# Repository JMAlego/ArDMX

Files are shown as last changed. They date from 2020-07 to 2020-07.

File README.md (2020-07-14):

# ArDMX

*DMX512 Interface Shield*

## Introduction
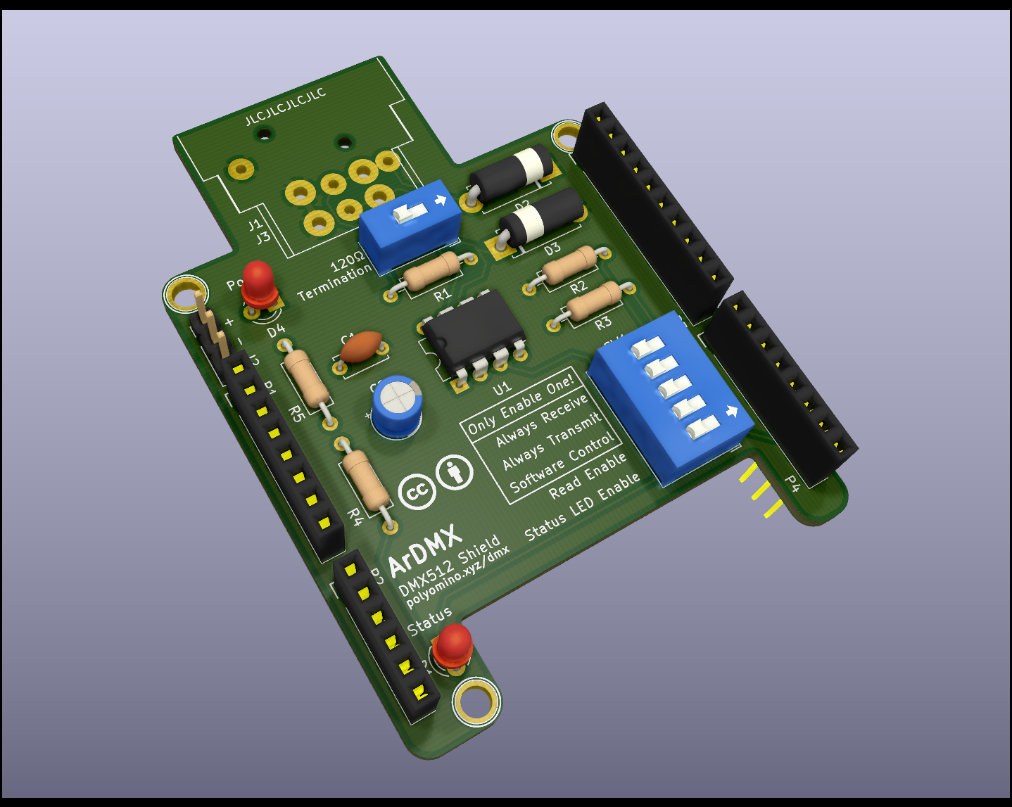
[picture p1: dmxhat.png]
Image of the DMX Shield


Following the creation of [AVR-DMX](https://github.com/JMAlego/AVR-DMX) for Arduino, I decided that my first foray into circuit board design should be the creation of a shield to work with AVR-DMX to allow proper interfacing of an Arduino to a DMX network.

**NB**: I have yet to actually get one of these made so who knows if it works, it's based on a perfboarded design that works correctly though.

## DIP Switches

- 120Ω Termination:
- Mode (only enable one unless you want a short):
  - Always Receive: Pull-down
  - Always Transmit: Pull-up
  - Software Control: Connect to pin 2
- Read Enable: Connect read output to pin 8
- Status LED Enable: Connect status LED to pin 9

## Optional Components

- D2 & D3 are only required for max voltage clamping on the DMX bus, if you're not worried about over/under-voltage then don't bother with them.
- SW2 & R1 are optional if you don't want 120Ω termination.
- J2 is not required if you don't want to use the outputs without the XLR connector.
- J1 is not required if you plan to use J2 to connect to the DMX network.
- Smoothing caps C1 & C2 are also optional if you're sure your input supply will be sufficiently smooth.
- D4 & R5 are optional if you don't want the power LED.
- Similarly, D1 & R4 are optional if you don't want the status LED.

## Rough Costing

It should be possible to build for around £10 or less (though you may need to make a few). You'll find the most expensive part is the Neutrik NC5FAH-DA (or compatible) XLR 5-pin connector.

As of revision 1.1 a cheaper option of using the 3-pin XLR Neutrik NC3FAH1-DA connector which the board now also supports.

## License

Hardware designs are licensed under the [Creative Commons Attribution 4.0 International Licence](https://creativecommons.org/licenses/by/4.0/).

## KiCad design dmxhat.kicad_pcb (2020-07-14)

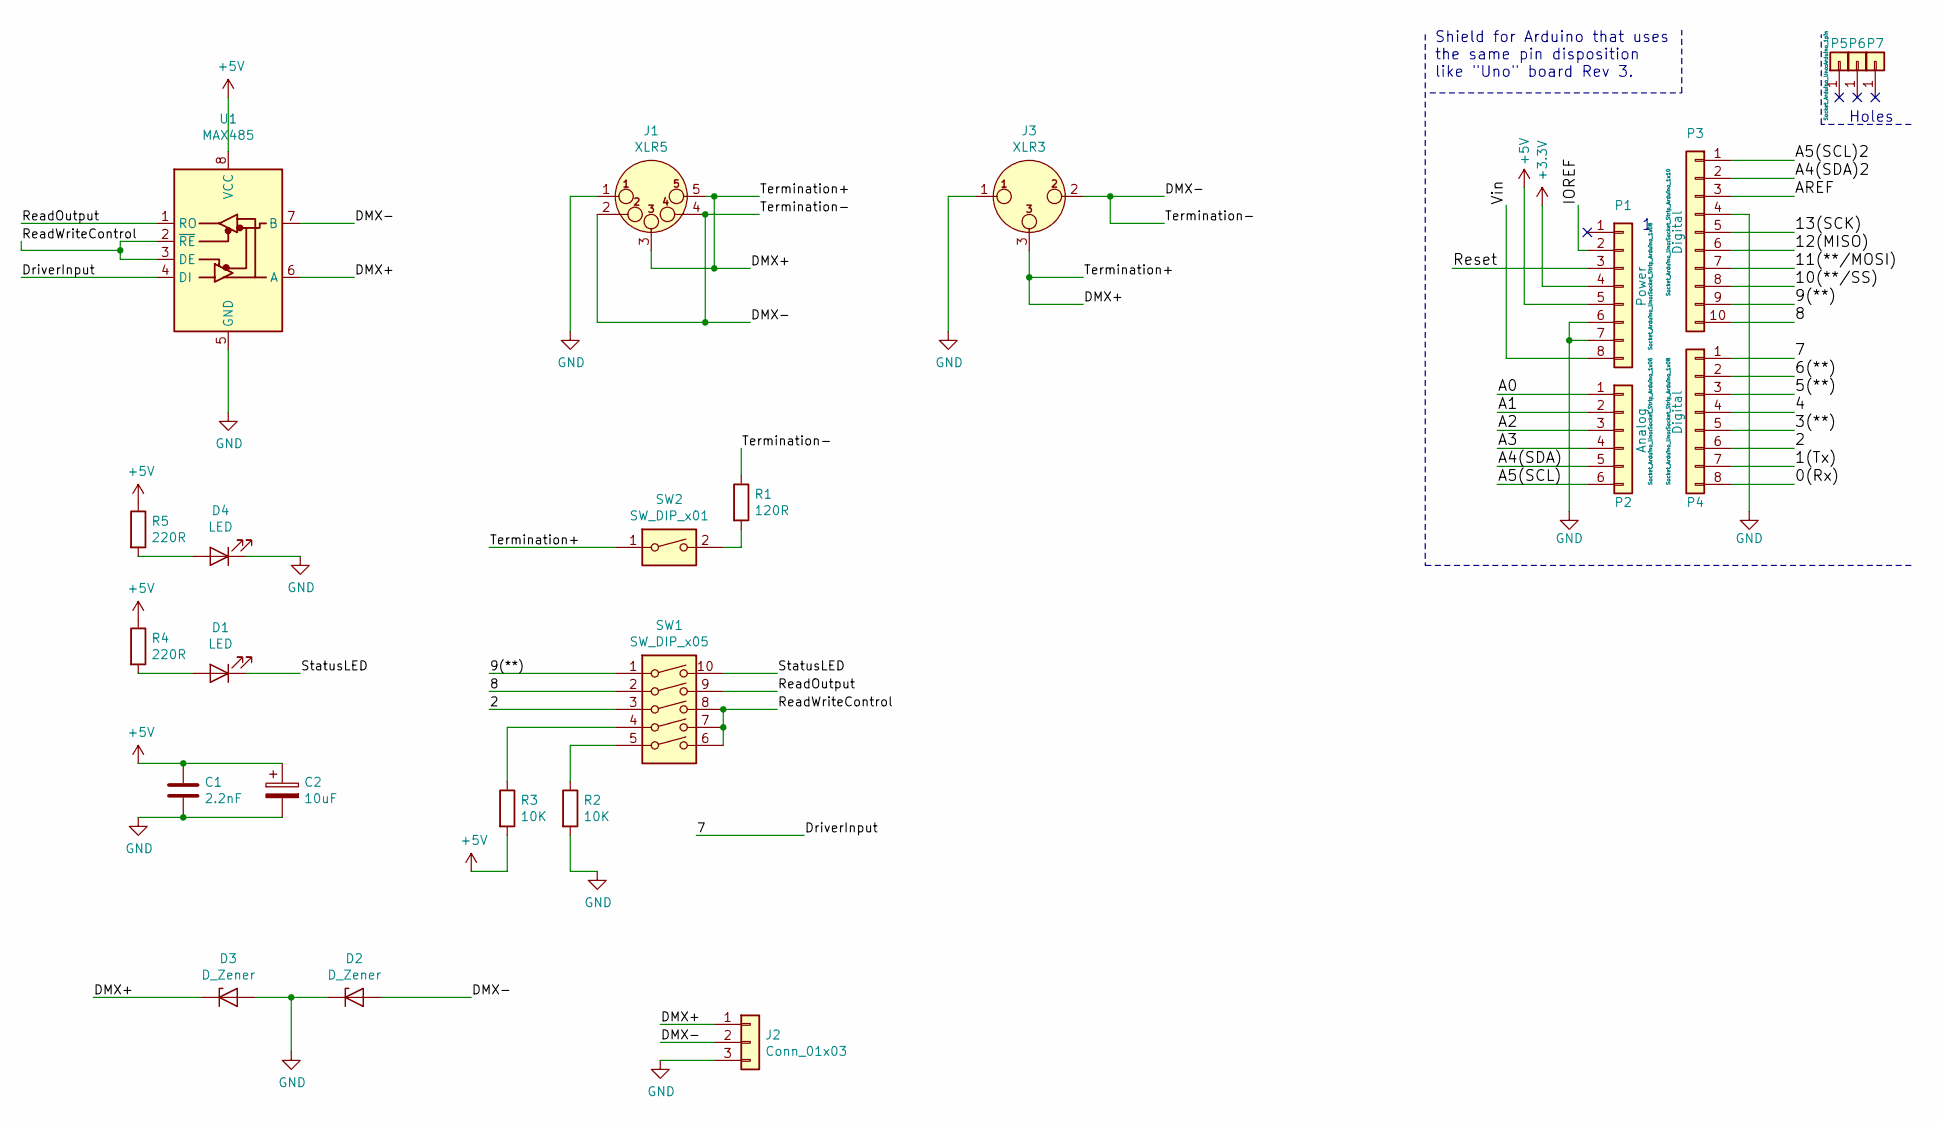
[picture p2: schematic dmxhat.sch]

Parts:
C1: 2.2nF; C_Disc_D5.0mm_W2.5mm_P5.00mm
C2: 10uF; CP_Radial_D5.0mm_P2.50mm
D1, D4: LED; LED_D3.0mm
D2, D3: D_Zener; D_5W_P12.70mm_Horizontal
J1: XLR5; Jack_XLR_Neutrik_NC5FAH-DA_Horizontal
J2: Conn_01x03; PinHeader_1x03_P2.54mm_Vertical
J3: XLR3; Jack_XLR_Neutrik_NC3FAH1-DA_Horizontal
P1: Power; Socket_Strip_Arduino_1x08
P2: Analog; Socket_Strip_Arduino_1x06
P3: Digital; Socket_Strip_Arduino_1x10
P4: Digital; Socket_Strip_Arduino_1x08
P5, P6, P7: CONN_01X01; Arduino_1pin
R1: 120R; R_Axial_DIN0207_L6.3mm_D2.5mm_P10.16mm_Horizontal
R2, R3: 10K; R_Axial_DIN0207_L6.3mm_D2.5mm_P10.16mm_Horizontal
R4, R5: 220R; R_Axial_DIN0207_L6.3mm_D2.5mm_P10.16mm_Horizontal
SW1: SW_DIP_x05; SW_DIP_SPSTx05_Slide_9.78x14.88mm_W7.62mm_P2.54mm
SW2: SW_DIP_x01; SW_DIP_SPSTx01_Slide_9.78x4.72mm_W7.62mm_P2.54mm
U1: MAX485; DIP-8_W7.62mm

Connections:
+3V3: P1.4
+5V: C1.1, C2.1, P1.5, R3.2, R4.1, R5.1, U1.8 (VCC)
/0(Rx): P4.8
/1(Tx): P4.7
/2: P4.6, SW1.3
/3(**): P4.5
/4: P4.4
/5(**): P4.3
/6(**): P4.2
/7: P4.1, U1.4 (DI)
/8: P3.10, SW1.2
/9(**): P3.9, SW1.1
/10(**/SS): P3.8
/11(**/MOSI): P3.7
/12(MISO): P3.6
/13(SCK): P3.5
/A0: P2.1
/A1: P2.2
/A2: P2.3
/A3: P2.4
/A4(SDA): P2.5
/A4(SDA)2: P3.2
/A5(SCL): P2.6
/A5(SCL)2: P3.1
/AREF: P3.3
/DMX+: D3.1 (K), J1.3, J1.5, J2.1, J3.3, SW2.1, U1.6 (A)
/DMX-: D2.2 (A), J1.2, J1.4 (P3), J2.2, J3.2, R1.1, U1.7 (B)
/IOREF: P1.2
/ReadOutput: SW1.9, U1.1 (RO)
/ReadWriteControl: SW1.6, SW1.7, SW1.8, U1.2 (~RE), U1.3 (DE)
/Reset: P1.3
/StatusLED: D1.1 (K), SW1.10
/Vin: P1.8
GND: C1.2, C2.2, D2.1 (K), D3.2 (A), D4.1 (K), J1.1, J1.G, J2.3, J3.1, P1.6, P1.7, P3.4, R2.2, U1.5 (GND)
unnamed: D1.2 (A), R4.2
unnamed: D4.2 (A), R5.2
unnamed: R1.2, SW2.2
unnamed: R2.1, SW1.5
unnamed: R3.1, SW1.4

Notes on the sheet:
Holes
Shield for Arduino that uses the same pin disposition like "Uno" board Rev 3.

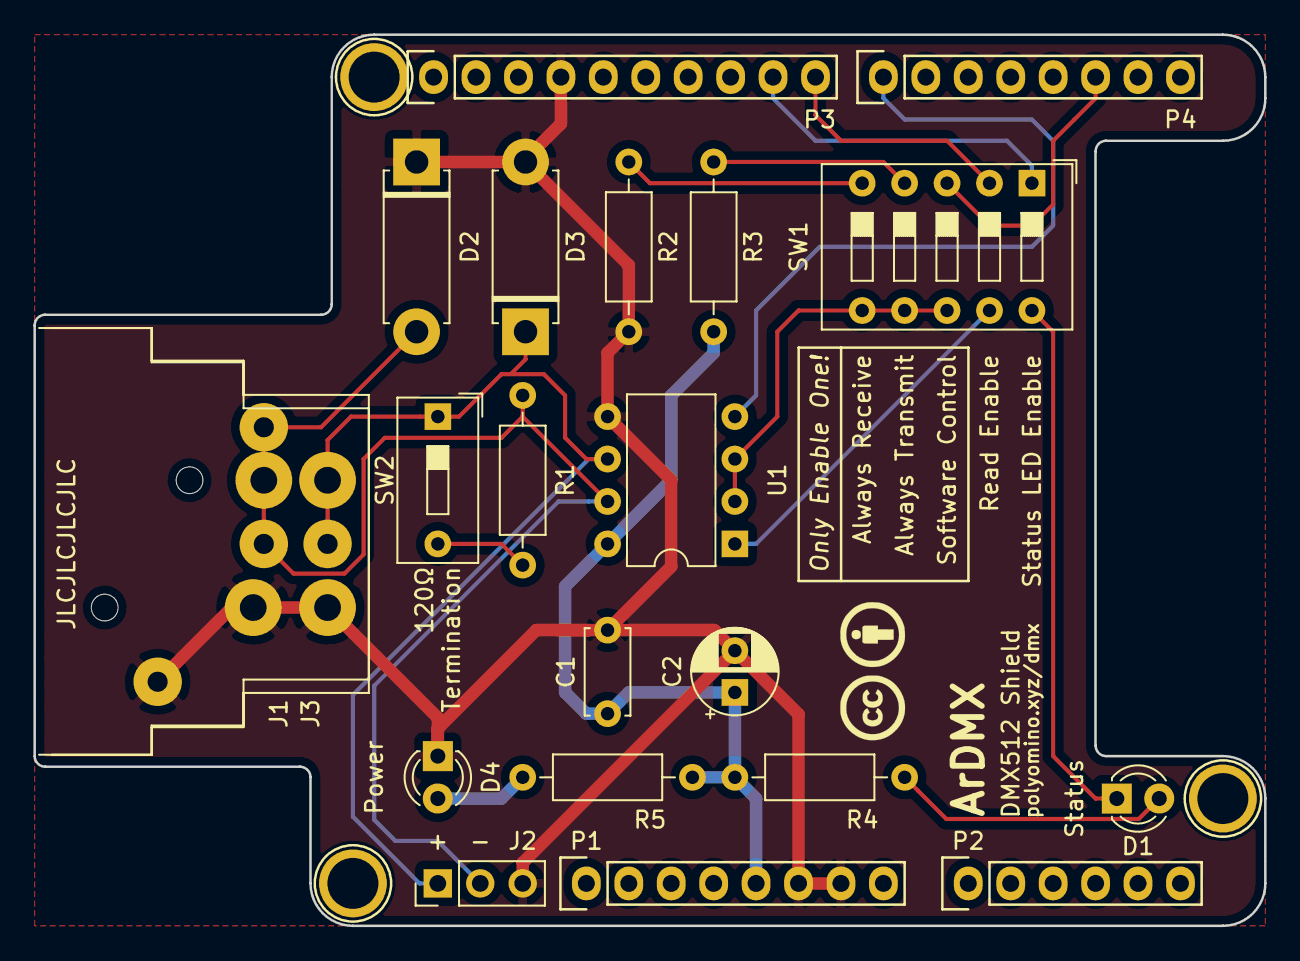
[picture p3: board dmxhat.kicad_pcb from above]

Board: 2 copper layers, 73.7 x 53.3 mm, 24 parts (0 on the bottom side), 16 nets.

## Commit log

2020-05-30 Updated Gerbers
    [dmxhat-B_Cu.gbr, dmxhat-B_SilkS.gbr, dmxhat-F_Cu.gbr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]
2020-05-30 Fix silk screen
    [dmxhat.kicad_pcb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]
2020-07-14 Update to revision 1.1
    [dmxhat-B_Cu.gbr, dmxhat-B_Mask.gbr, dmxhat-B_SilkS.gbr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]
